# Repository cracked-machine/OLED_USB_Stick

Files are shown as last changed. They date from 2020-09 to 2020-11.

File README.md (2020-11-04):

 ## OLED-USB Stick

Required Kicad Hardware library: https://github.com/cracked-machine/KicadLibrary

Related SW project: https://github.com/cracked-machine/OLED_USB_Stick_SW

This project was an excuse to play with the FT232RL chips. I thought it would be fun to have a USB stick device that would:

- Take input text from a TTY and send it to an OLED display
- Allow firmware update via the same USB plug.



### Design implementation

There are four LEDs on the top. These indicate:

- USB->UART transmit/receive signals
- USB 5V bus power
- USB Host suspend mode

Note, the I2C connector has pull-up resistors (R6/R7) on the SCL and SDA lines. These are not required when using the OLED module since they are included on the module already. However, adding the pull-up resistors allows a direct interface to the MCU I2C interface. So, if you omit the OLED display, you can talk directly to the onboard MCU using an external device via I2C.

U1 is the FTDI FT232RL and handles the USB->RS232 interface.

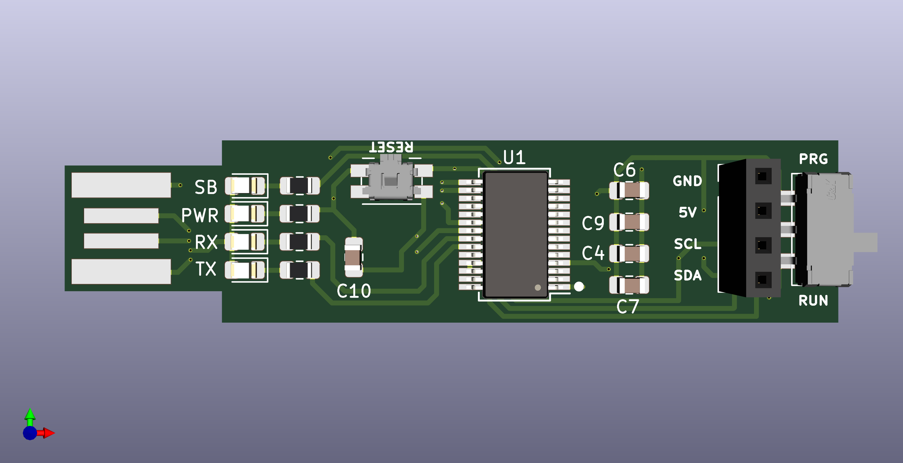
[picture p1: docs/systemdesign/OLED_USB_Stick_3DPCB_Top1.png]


U3 is the STM32F051 MCU. It's UART TX/RX IO pins are connected directly to the output of the U1 RXD/TXD IO pins.  A mode switch connects the BOOT0 pin of the MCU to either 3V3 or GND, which initialises the MCU using either the bootloader (sysmem) or user application (flash). When updating the firmware the PRG option should be selected so that the bootloader can be accessed and the user application downloaded to flash. After switching between modes the reset button should be pressed before continuing.

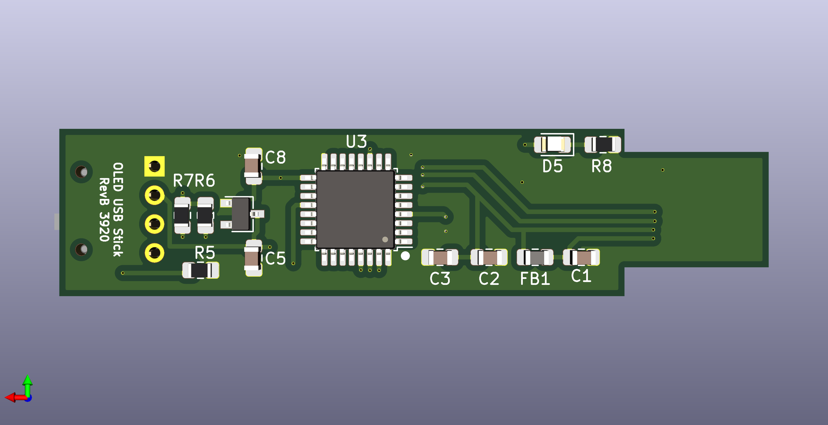
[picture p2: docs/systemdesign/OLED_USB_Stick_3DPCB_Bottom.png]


There is also an optional LED (D5) on the back of the PCB to allow quick debug testing, as there is no access to the SWD debug interface.

The 5V USB vbus line is regulated down to 3V3 (via a SOT23 regulator) to supply the MCU.

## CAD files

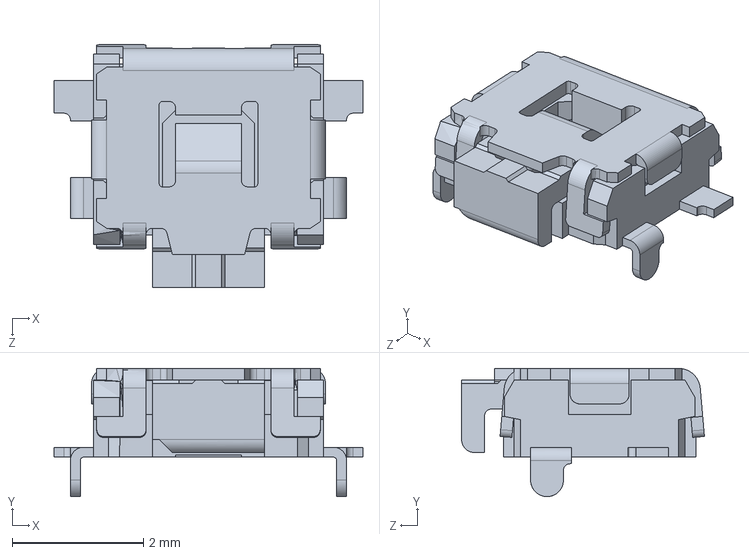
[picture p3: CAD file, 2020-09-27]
kicad/RevB/3D/EVQ-9P7_P34-01P.STEP
4.70 x 1.95 x 3.69 mm

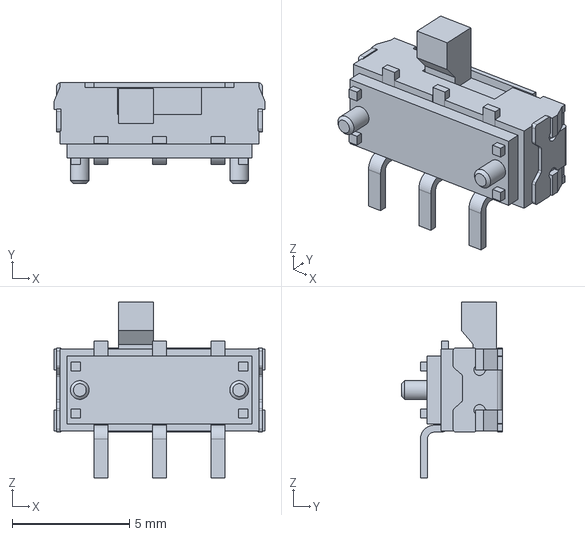
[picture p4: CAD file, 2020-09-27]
kicad/RevB/3D/JS102011SAQN.stp
9.00 x 4.30 x 7.50 mm

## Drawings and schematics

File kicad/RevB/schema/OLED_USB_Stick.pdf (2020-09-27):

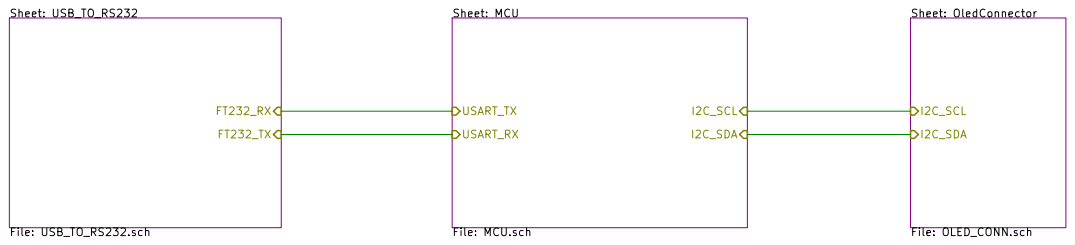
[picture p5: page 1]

Sheet: OledConnector File: OLED_CONN.sch

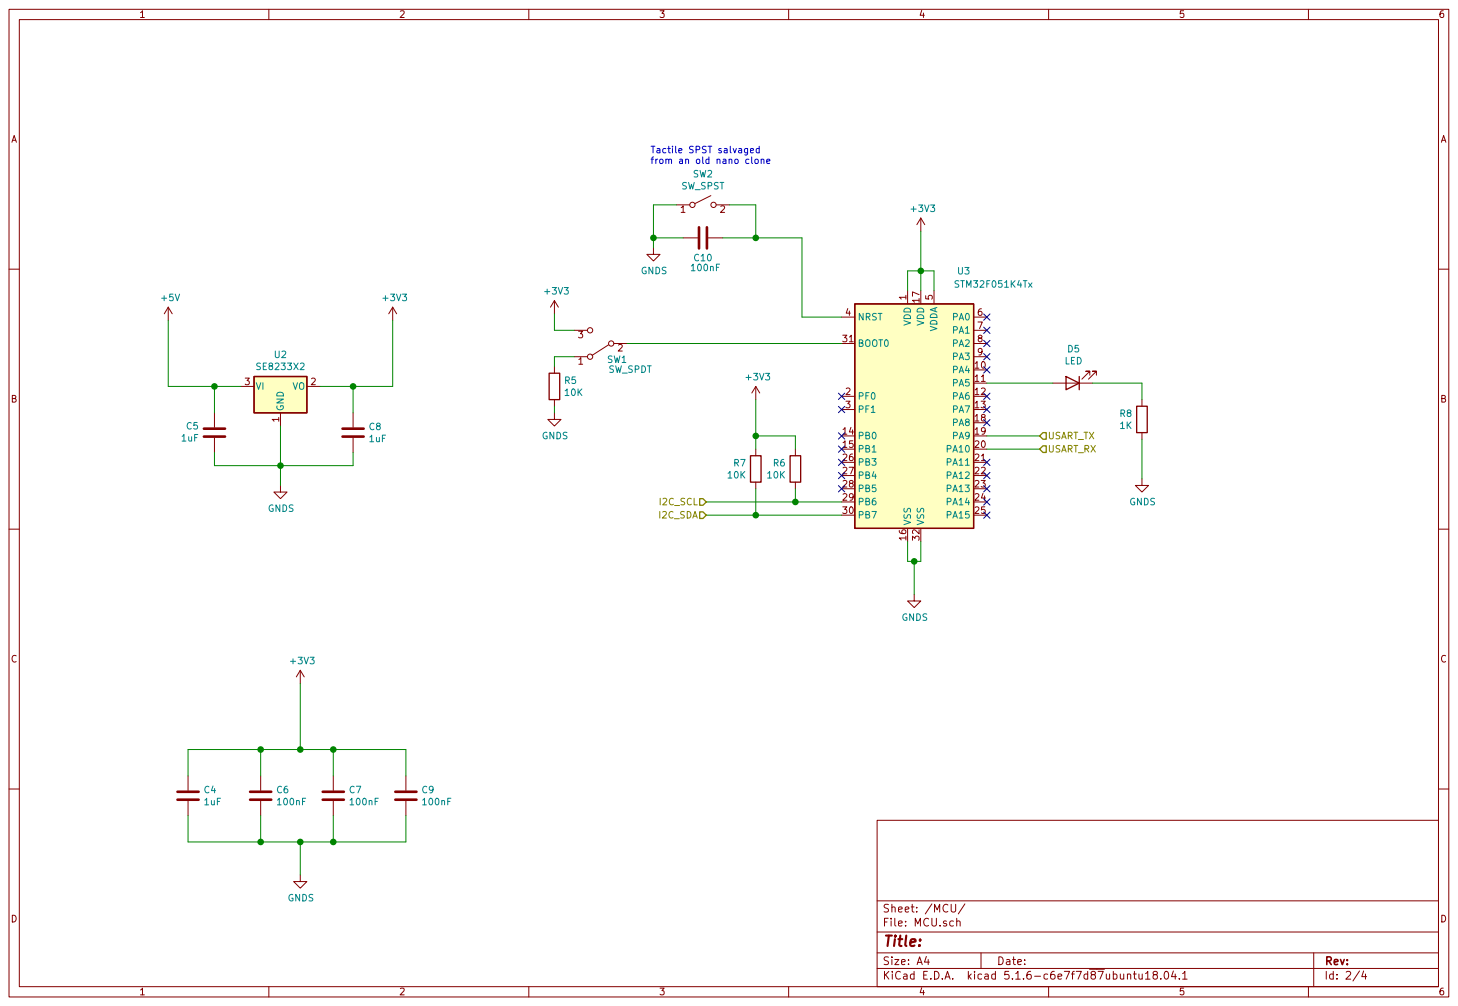
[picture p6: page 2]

Tactile SPST salvaged
from an old nano clone

1 PA4 10 PA5 11 PA6 12 PA7 13 PB0 14 PB1 15 VSS 16 VDD 17 PA8 18 PA9 19 PF0 2 PA10 20 PA11 21 PA12 22 PA13 23 PA14 24 PA15 25 PB3 26 PB4 27 PB5 28 PB6 29 PF1 3 PB7 30 BOOT0 31 VSS 32 NRST 4 VDDA

Id: 2/4 Title: File: MCU.sch Sheet: /MCU/

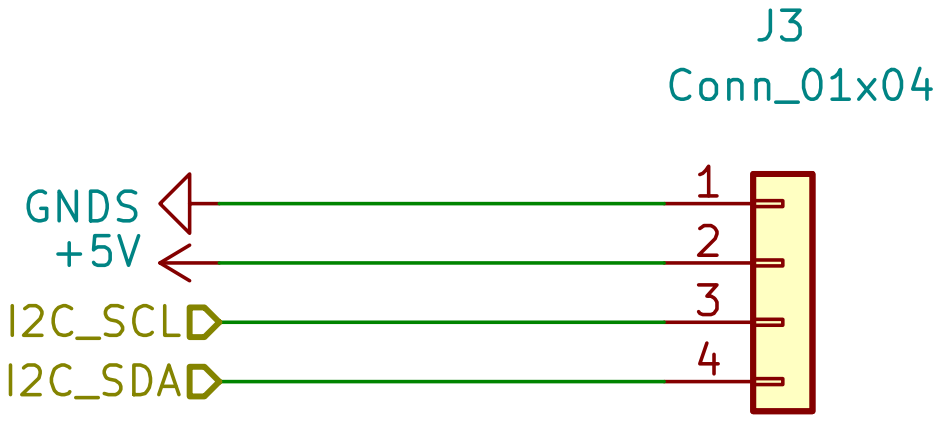
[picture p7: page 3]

File: OLED_CONN.sch Sheet: /OledConnector/
Id: 3/4 Title:

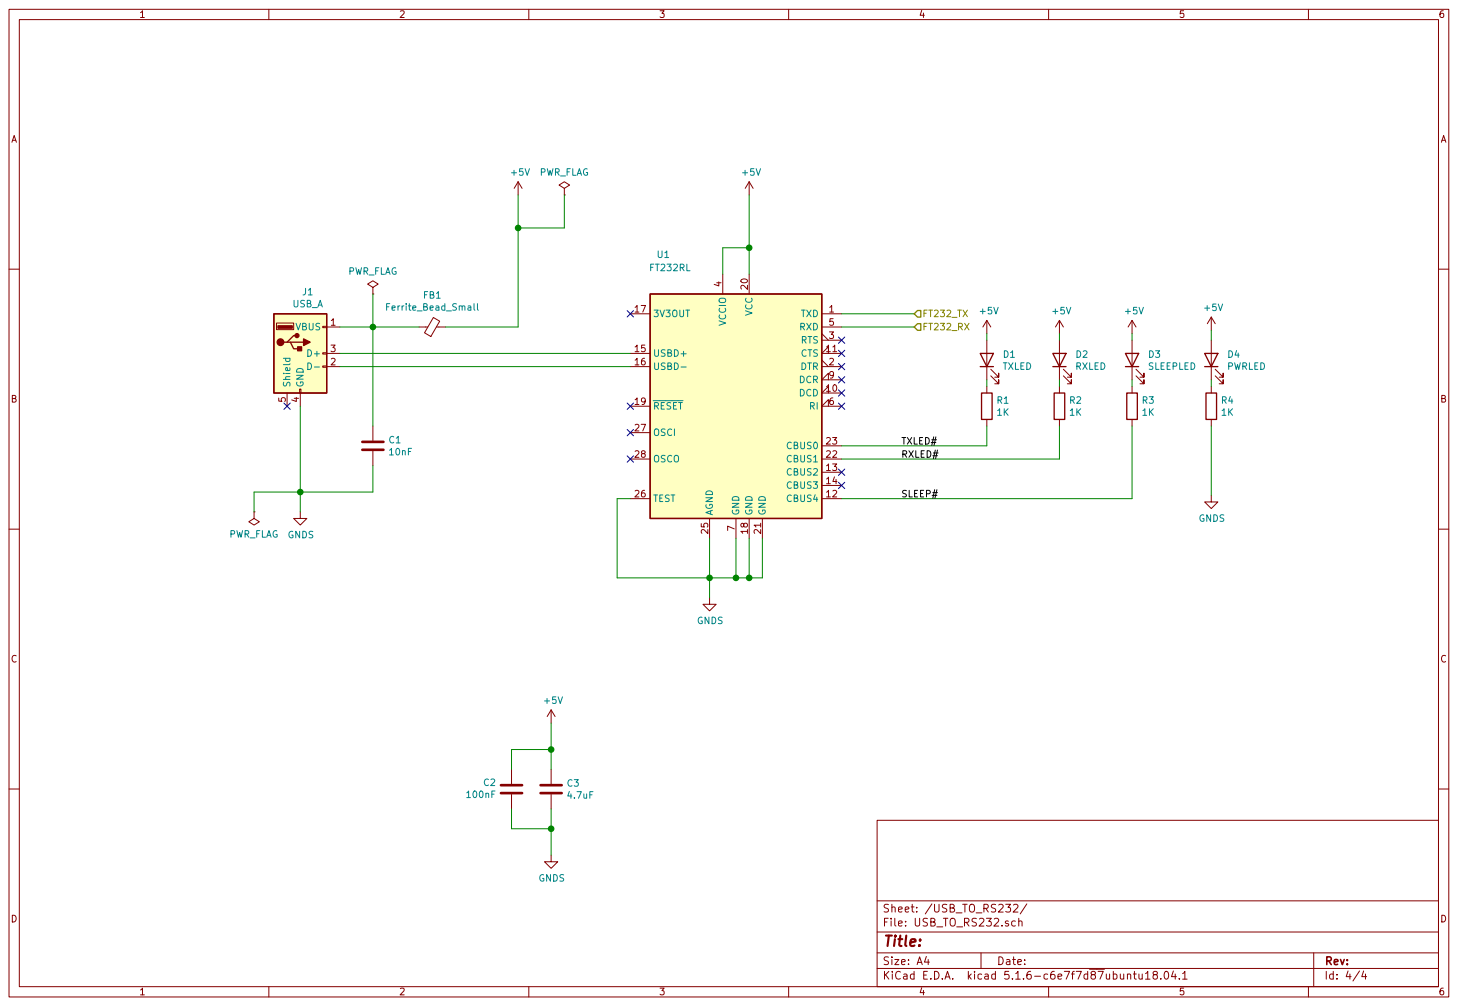
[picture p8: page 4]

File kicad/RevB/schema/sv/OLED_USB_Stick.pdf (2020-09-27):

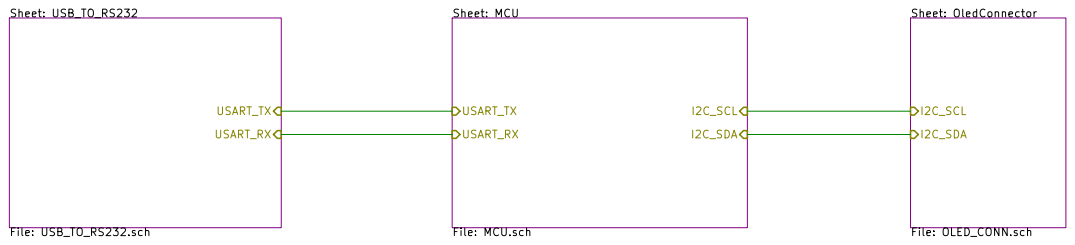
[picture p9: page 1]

Sheet: OledConnector File: OLED_CONN.sch

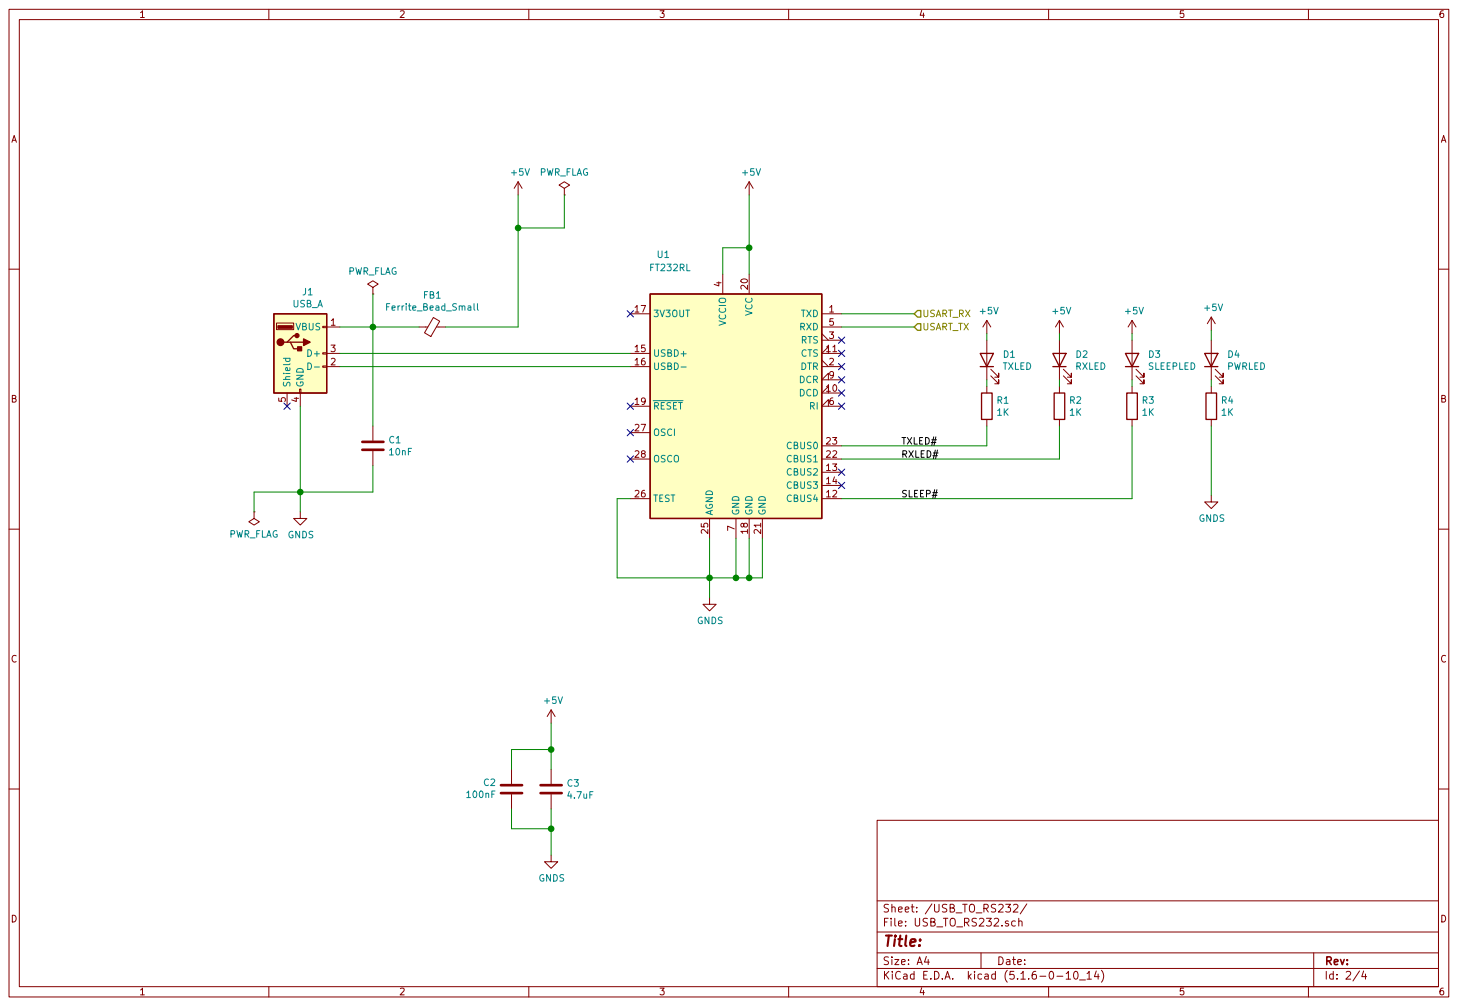
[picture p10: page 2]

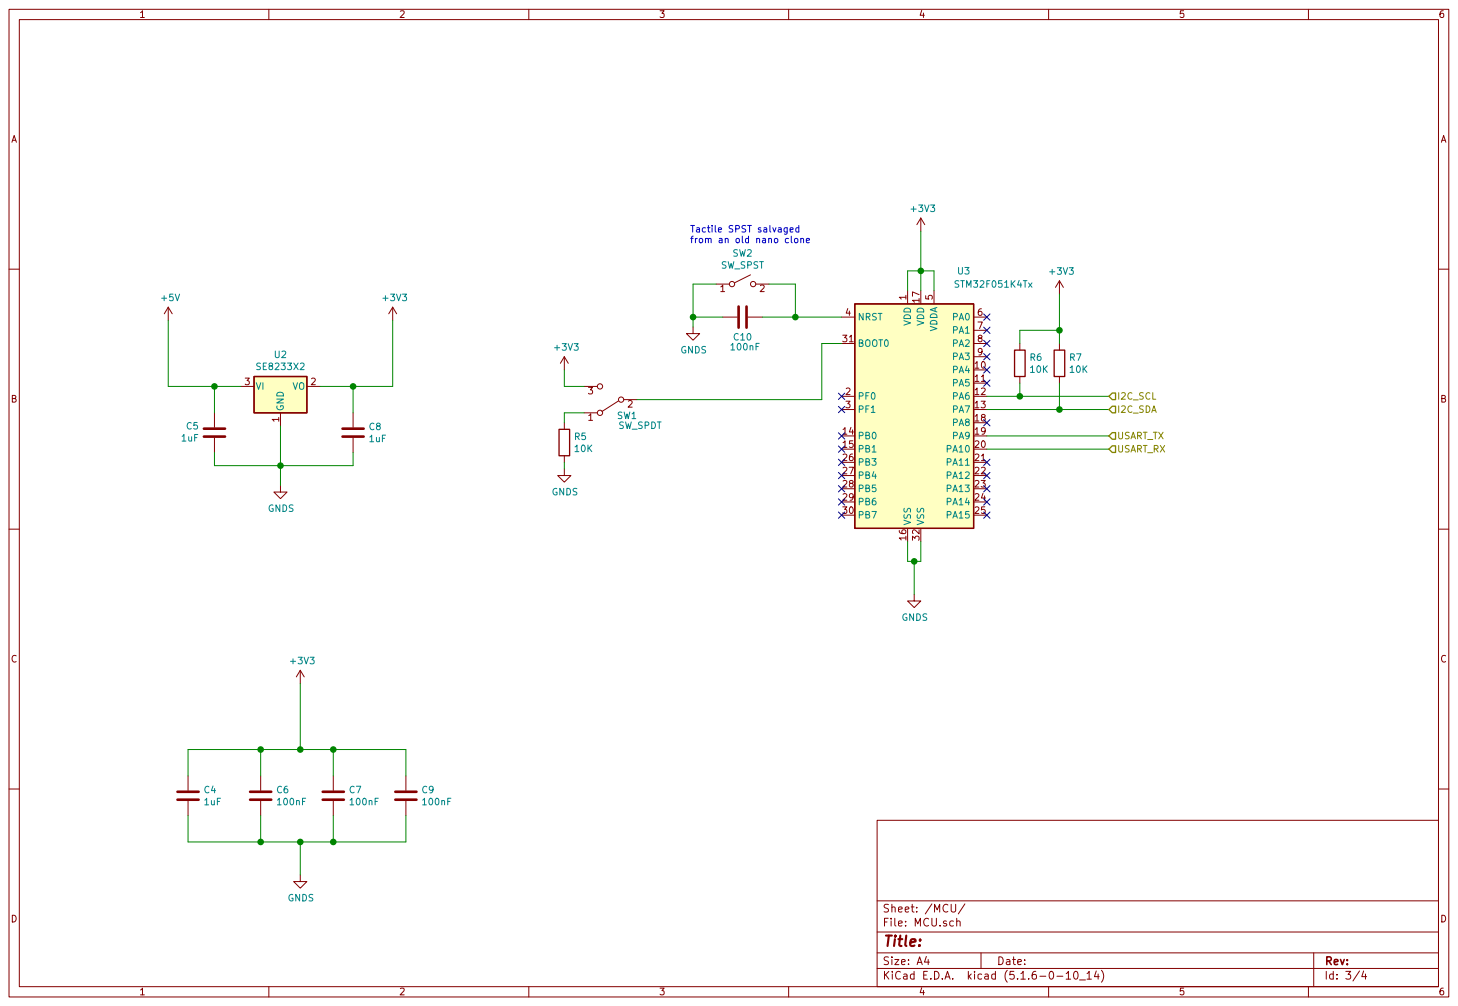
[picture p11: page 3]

I2C_SCL Tactile SPST salvaged
from an old nano clone

1 PA4 10 PA5 11 PA6 12 PA7 13 PB0 14 PB1 15 VSS 16 VDD 17 PA8 18 PA9 19 PF0 2 PA10 20 PA11 21 PA12 22 PA13 23 PA14 24 PA15 25 PB3 26 PB4 27 PB5 28 PB6 29 PF1 3 PB7 30 BOOT0 31 VSS 32 NRST 4 VDDA

Id: 3/4 Title: File: MCU.sch Sheet: /MCU/


File: OLED_CONN.sch Sheet: /OledConnector/
Id: 4/4 Title:

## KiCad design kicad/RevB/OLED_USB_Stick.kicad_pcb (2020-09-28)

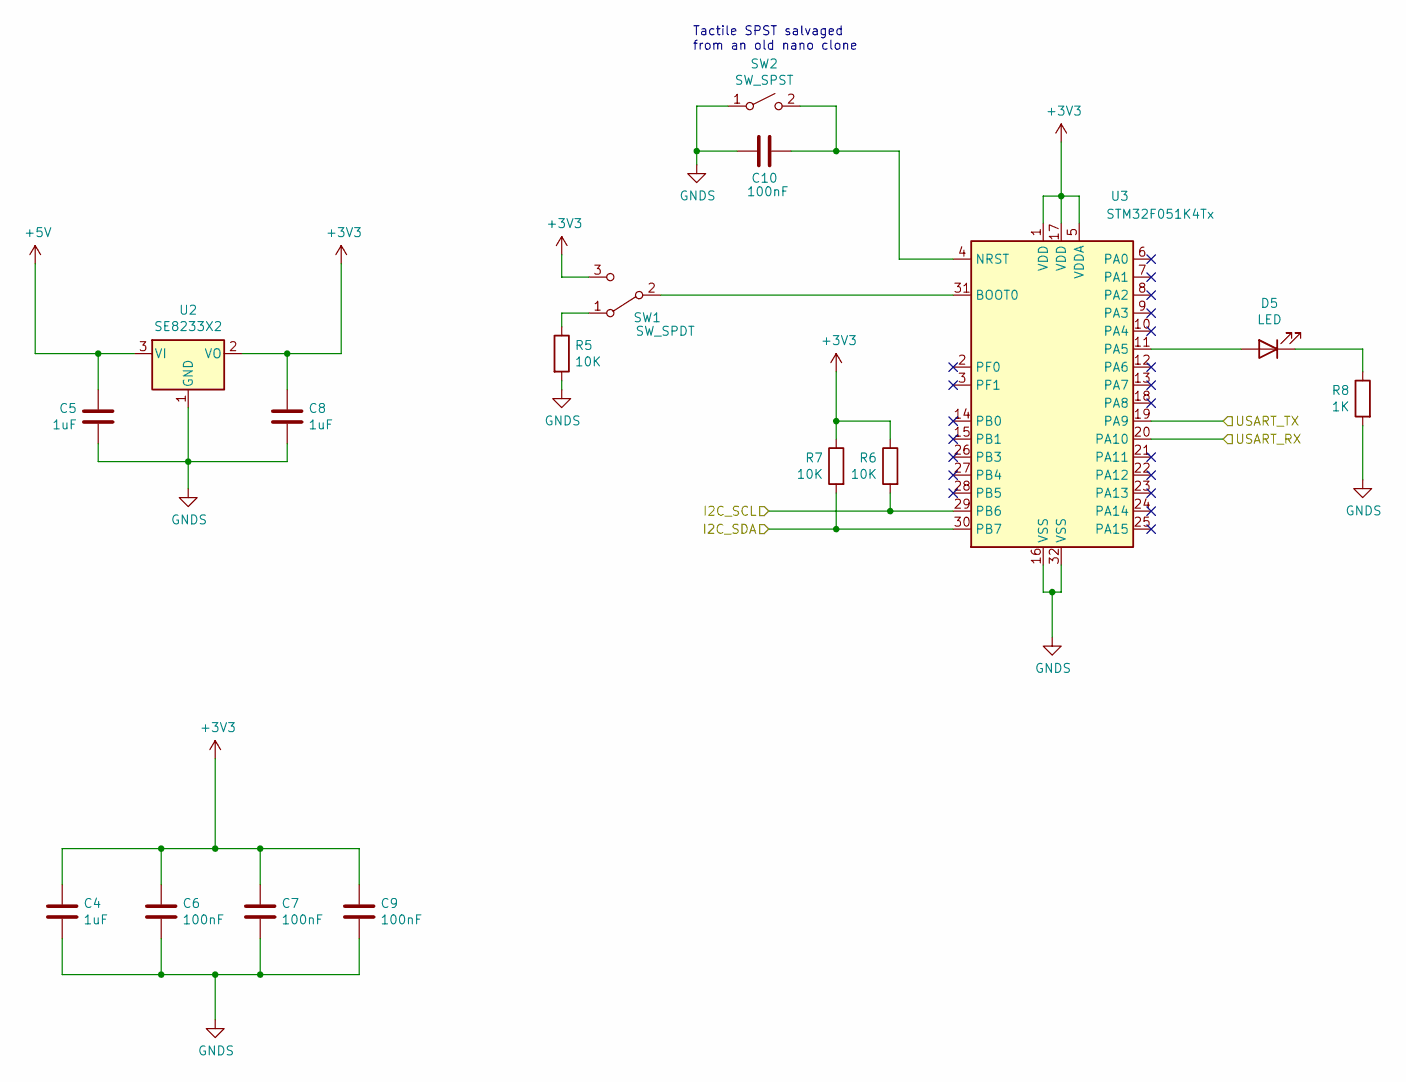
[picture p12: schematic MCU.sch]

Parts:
C4, C5, C8: 1uF; C_0805_2012Metric_Pad1.15x1.40mm_HandSolder
C6, C7, C9, C10: 100nF; C_0805_2012Metric_Pad1.15x1.40mm_HandSolder
D5: LED; LED_0805_2012Metric_Pad1.15x1.40mm_HandSolder
R5, R6, R7: 10K; R_0805_2012Metric_Pad1.15x1.40mm_HandSolder
R8: 1K; R_0805_2012Metric_Pad1.15x1.40mm_HandSolder
SW1: SW_SPDT; JS102011SAQN
SW2: SW_SPST; Panasonic_EVQPUK_EVQPUB
U2: SE8233X2; TSOT-23
U3: STM32F051K4Tx; LQFP-32_7x7mm_P0.8mm

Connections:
+3V3: C4.1, C6.1, C7.1, C8.1, C9.1, R6.1, R7.1, SW1.3 (C), U2.2 (VO), U3.1 (VDD), U3.5 (VDDA), U3.17 (VDD)
+5V: C5.2, U2.3 (VI); also elsewhere on the board
/MCU/I2C_SCL: R6.2, U3.29 (PB6); also elsewhere on the board
/MCU/I2C_SDA: R7.2, U3.30 (PB7); also elsewhere on the board
/USB_TO_RS232/FT232_RX: U3.19 (PA9); also elsewhere on the board
/USB_TO_RS232/FT232_TX: U3.20 (PA10); also elsewhere on the board
GNDS: C4.2, C5.1, C6.2, C7.2, C8.2, C9.2, C10.2, R5.2, R8.2, SW2.1 (A), U2.1 (GND), U3.16 (VSS), U3.32 (VSS); also elsewhere on the board
unnamed: C10.1, SW2.2 (B), U3.4 (NRST)
unnamed: D5.1 (K), R8.1
unnamed: D5.2 (A), U3.11 (PA5)
unnamed: R5.1, SW1.1 (A)
unnamed: SW1.2 (B), U3.31 (BOOT0)

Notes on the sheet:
Tactile SPST salvaged from an old nano clone

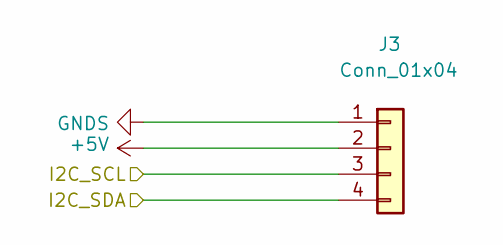
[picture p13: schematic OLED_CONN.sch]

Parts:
J3: Conn_01x04; PinHeader_1x04_P2.54mm_Vertical

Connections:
+5V: J3.2; also elsewhere on the board
/MCU/I2C_SCL: J3.3; also elsewhere on the board
/MCU/I2C_SDA: J3.4; also elsewhere on the board
GNDS: J3.1; also elsewhere on the board

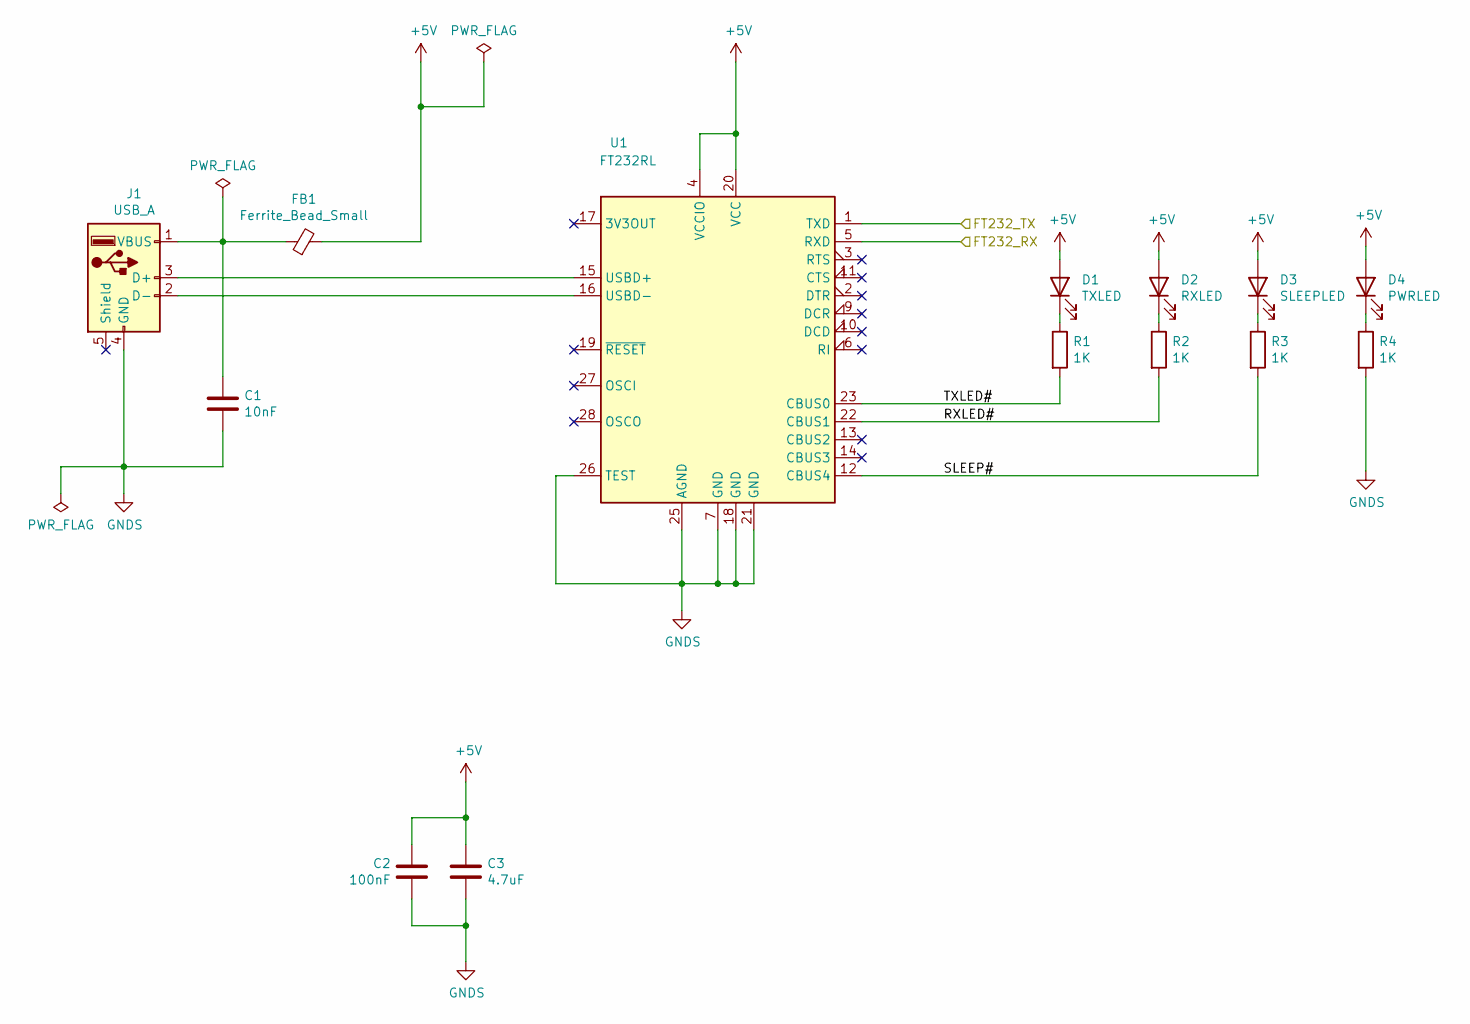
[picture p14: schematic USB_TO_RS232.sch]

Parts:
C1: 10nF; C_0805_2012Metric_Pad1.15x1.40mm_HandSolder
C2: 100nF; C_0805_2012Metric_Pad1.15x1.40mm_HandSolder
C3: 4.7uF; C_0805_2012Metric_Pad1.15x1.40mm_HandSolder
D1: TXLED; LED_0805_2012Metric_Pad1.15x1.40mm_HandSolder
D2: RXLED; LED_0805_2012Metric_Pad1.15x1.40mm_HandSolder
D3: SLEEPLED; LED_0805_2012Metric_Pad1.15x1.40mm_HandSolder
D4: PWRLED; LED_0805_2012Metric_Pad1.15x1.40mm_HandSolder
FB1: Ferrite_Bead_Small; L_0805_2012Metric_Pad1.15x1.40mm_HandSolder
J1: USB_A; USB_A_Plug_ConnectorLess
R1, R2, R3, R4: 1K; R_0805_2012Metric_Pad1.15x1.40mm_HandSolder
U1: FT232RL; SSOP-28_5.3x10.2mm_P0.65mm

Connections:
+5V: C2.2, C3.1, D1.2 (A), D2.2 (A), D3.2 (A), D4.2 (A), FB1.2, U1.4 (VCCIO), U1.20 (VCC); also elsewhere on the board
/USB_TO_RS232/FT232_RX: U1.5 (RXD); also elsewhere on the board
/USB_TO_RS232/FT232_TX: U1.1 (TXD); also elsewhere on the board
/USB_TO_RS232/RXLED#: R2.2, U1.22 (CBUS1)
/USB_TO_RS232/SLEEP#: R3.2, U1.12 (CBUS4)
/USB_TO_RS232/TXLED#: R1.2, U1.23 (CBUS0)
GNDS: C1.2, C2.1, C3.2, J1.4 (GND), R4.2, U1.7 (GND), U1.18 (GND), U1.21 (GND), U1.25 (AGND), U1.26 (TEST); also elsewhere on the board
unnamed: C1.1, FB1.1, J1.1 (VBUS)
unnamed: D1.1 (K), R1.1
unnamed: D2.1 (K), R2.1
unnamed: D3.1 (K), R3.1
unnamed: D4.1 (K), R4.1
unnamed: J1.2 (D-), U1.16 (USBD-)
unnamed: J1.3 (D+), U1.15 (USBD+)

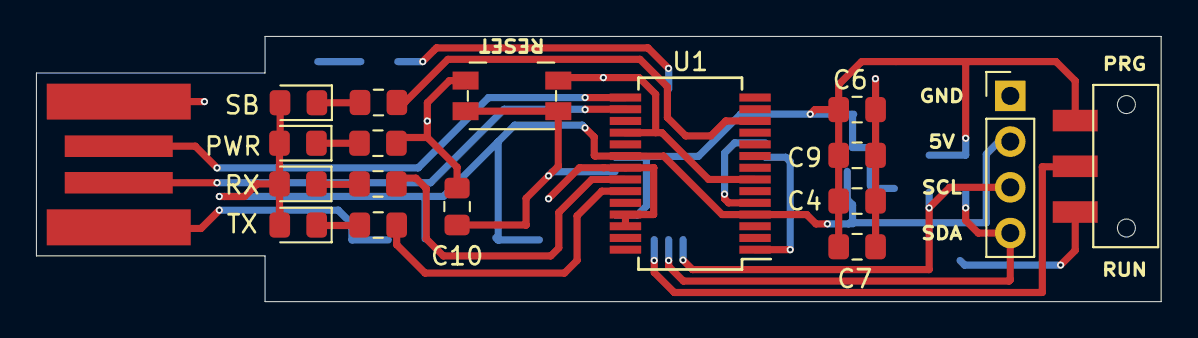
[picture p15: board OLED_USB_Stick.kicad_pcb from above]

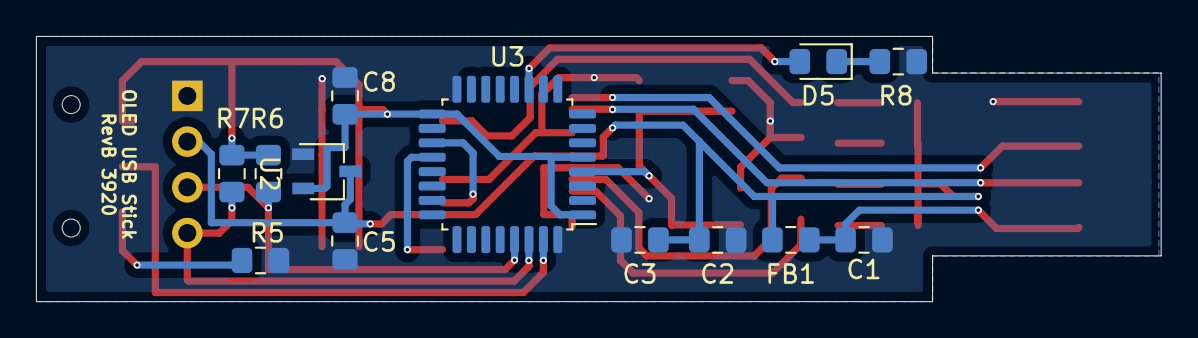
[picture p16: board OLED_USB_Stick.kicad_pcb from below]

Board: 2 copper layers, 62.5 x 14.7 mm, 31 parts (13 on the bottom side), 22 nets.

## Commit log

2020-09-26 first schema draft
    [MCU.sch, OLED_CONN.sch, OLED_USB_Stick.kicad_pcb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]
2020-09-27 completed RevB
    [JS102011SAQN.stp, MCU.sch, OLED_CONN.sch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]
2020-09-27 updated revb hw
    - Added pull up resistors to i2C bus (allows direct connection to mcu from oled port)
    [MCU.sch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]
2020-09-27 updated hw
    - corrected i2c pins
    - changed reset btn to horizontal mount
    [EVQ-9P7_P34-01P.STEP, MCU.sch, OLED_CONN.sch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]
